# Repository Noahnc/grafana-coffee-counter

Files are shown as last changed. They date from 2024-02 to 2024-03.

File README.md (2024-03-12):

# Grafana Coffee Counter

This project contains all resources to build a Grafana Cloud Coffee Counter.
The coffee counter consists of a custom PCB with an ESP32 and an DFRobot Vibration Sensor.

## How it works

The vibration sensor attached to the coffee machine is connected to the ESP32 and reads the vibration state. If vibration is detected, the ESP32 will count the amount of time the vibration sensor is continuously active. If the vibration sensor is active for more than 8 seconds, the vibration is consideres as a coffee and counters of a Prometheus histogram are increased. Every 60s, a new Time Series is created for the coffee histogram and some other system metrics. The data is then sent to Grafana Cloud Mimir using Prometheus Remote Write. Since the library used for the Prometheus Remote Write is fully Prometheus compatible, the data can technically also be sent to any other Prometheus compatible system. Just make sure to change the URL and the root certificate accordingly.

## Hardware

The following hardware is used for this project:

- https://wiki.dfrobot.com/Vibration_Sensor_SKU_SEN0433
- ESP32 WROVER-E
- Custom PCB (see `./easy_eda`)

## Build Flags

To build this project, you have to create a file called `user_config.ini` in the Project root directory. This file contains the following build flags:

```INI
[user_config]
build_flags =
	-D ENV_GRAFANA_USER=\"<Grafana user>\"
	-D ENV_GRAFANA_PASSWORD=\"<Grafana password>=\"
	-D ENV_WIFI_SSID=\"<Wifi SSID>\"
	-D ENV_WIFI_PASSWORD=\"<Wifi password>!\"
	-D ENV_LABEL_SITE=\"<label value for label SITE>\"
	-D ENV_LABEL_FLOOR=\"<labe value for label FLOOR>\"
	-D ENV_ENABLE_REV2_SENSORS=\"<set true if rev2 board>\"
```

### Hardware & Schema

The design of the custom PCB can be found in the folder `./easy_eda`. The design was created with [EasyEDA](https://easyeda.com/).
In addition to the custom PCB, there are STL files for a 3D-printed case in the folder `./3d_print`.

## CP2102N: USB to UART

The USB-to-UART chip `CP2102N` used in the schema under `./easy_eda` is configured using the [Simplicity Studio Software](https://www.silabs.com/developers/simplicity-studio) from Silicon Labs.

In `./cp2102n_configuration` there is a configuration file that can be played onto the chip with Simplicity Studio Software to set the GPIO configuration for the LED `TXT` and `RXT` and to set device information for the USB protocol. See also [Application Note AN721](https://www.silabs.com/documents/public/application-notes/AN721.pdf) for instructions.

Under Linux it may be necessary to set the execute flag manually for some files:

`chmod -x ./offline/ffd/xpress_configurator/cp210x_base/bin/Linux/*`

In addition, it should be checked whether all dependencies are available:

`ldd ./offline/ffd/xpress_configurator/cp210x_base/bin/Linux/cp210xcfg`

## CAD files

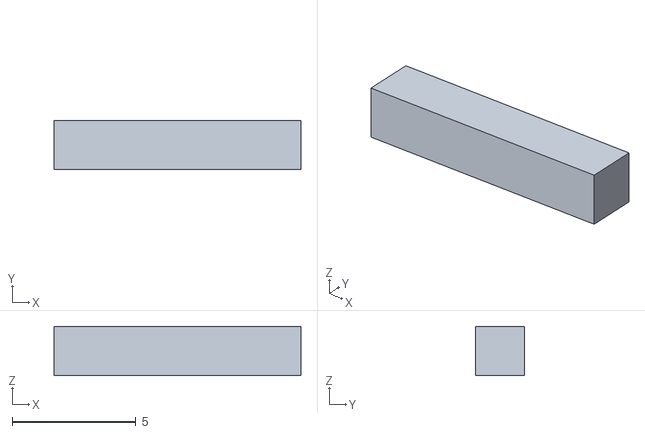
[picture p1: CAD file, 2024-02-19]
3d_print_case/coffee_counter_case_lid.stl
10.0 x 2.00 x 2.00

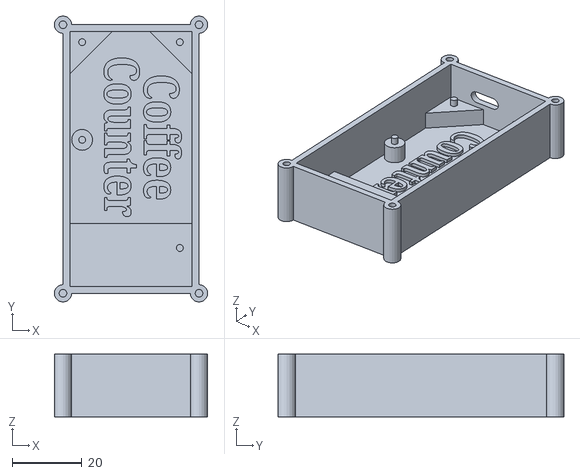
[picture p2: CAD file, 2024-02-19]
3d_print_case/coffee_counter_case.stl
44.0 x 82.0 x 18.0

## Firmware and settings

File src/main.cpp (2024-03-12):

#include <Arduino.h>
#include <PromLokiTransport.h>
#include <PrometheusArduino.h>
#include <config.h>
#include <tuple>
#include <stdio.h>
#include <string>
#include <vector>
#include <sstream>
#include <Wire.h>
#include <arduino-sht.h>
#include <vibration.h>
#include <transport.h>
#include <prometheus_histogram.h>
#include <tuple>
#include "esp32-hal-cpu.h"

// Increase stack size for the main loop since the default 8192 bytes are not enough
SET_LOOP_TASK_STACK_SIZE(32768);

// Function prototypes
#ifdef __cplusplus
  extern "C" {
#endif
  uint8_t temprature_sens_read(); // ES32 provided function to read internal temperature
#ifdef __cplusplus
}
#endif

bool performRemoteWrite();
void handleSampleIngestion();
void handleMetricsSend();
void ingestMetricSample(TimeSeries &ts, int64_t timestamp, double value, String name);
std::vector<std::string> setupLabels();
std::string joinLabels(const std::vector<std::string> &strings);
std::tuple<double, double> getTemperatureAndHumidity();


// I2C Bus & Temp/Humitity sensor
// Do not use bus_num=0 here. Bus 0 seems already to be used by subcomponent of PrometheusArduino or PromLokiTransport.
// Using Bus 1 instead.
TwoWire wire = TwoWire(1);
SHTSensor *sht31 = nullptr;

// Setup time variables
int64_t start_time_unix_ms = 0;
int64_t run_time_ms = 0;
int64_t current_cicle_start_time_unix_ms = 0;
int64_t last_metric_ingestion_unix_ms = 0;
int64_t last_remote_write_unix_ms = 0;

// int to count remote write failures
int remote_write_failures = 0;

// The write request that will be used to send the metrics to Prometheus. For every Histogram you need to add 3 + number of buckets timeseries
WriteRequest req(23, 12288);

// TimeSeries and labels
const char *labels;
Prometheus_Histogram *coffees_consumed = nullptr;
TimeSeries *system_memory_free_bytes = nullptr;
TimeSeries *system_memory_total_bytes = nullptr;
TimeSeries *system_network_wifi_rssi = nullptr;
TimeSeries *system_largest_heap_block_size_bytes = nullptr;
TimeSeries *system_run_time_ms = nullptr;
TimeSeries *system_remote_write_failures_count = nullptr;
TimeSeries *system_cpu_temperature = nullptr;
TimeSeries *system_cpu_clock = nullptr;
TimeSeries *temperature = nullptr;
TimeSeries *humidity = nullptr;

// helper services
hw_timer_t *timer0 = timerBegin(0, 80, true); // timer 0 of esp32 for vibration detection
Vibration *vibration = nullptr;
Transport *transport = nullptr;

void setup()
{
  pinMode(VIBRATION_SENSOR_PIN, INPUT);
  pinMode(VIBRATION_DETECTION_LED_VCC, OUTPUT);
  pinMode(WIFI_STATUS_LED_VCC, OUTPUT);
  pinMode(SYS_STATUS_LED_VCC, OUTPUT);

  // Setup serial
  Serial.begin(SERIAL_BAUD);
  while (!Serial)
    ;

  Serial.println("Starting up coffee counter ...");
  Serial.println("WiFi SSID: " + String(WIFI_SSID));

  std::vector<std::string> labelVector = setupLabels();
  std::string labelString = joinLabels(labelVector);
  labels = labelString.c_str();

  if (DEBUG)
    Serial.println("Labels: " + String(labels));

  // TimeSeries that hold 10 samples. Make sure to set sample_ingestation rate and remote_write_interval accordingly
  coffees_consumed = new Prometheus_Histogram("CMI_coffees_consumed", labels, TIME_SERIES_SAMPLE_COUNT, 12000, 4000, 10);
  system_memory_free_bytes = new TimeSeries(TIME_SERIES_SAMPLE_COUNT, "ESP32_system_memory_free_bytes", labels);
  system_memory_total_bytes = new TimeSeries(TIME_SERIES_SAMPLE_COUNT, "ESP32_system_memory_total_bytes", labels);
  system_network_wifi_rssi = new TimeSeries(TIME_SERIES_SAMPLE_COUNT, "ESP32_system_network_wifi_rssi", labels);
  system_cpu_temperature = new TimeSeries(TIME_SERIES_SAMPLE_COUNT, "ESP32_system_cpu_temperature_celsius", labels);
  system_cpu_clock = new TimeSeries(TIME_SERIES_SAMPLE_COUNT, "ESP32_system_cpu_clock_mhz", labels);
  system_largest_heap_block_size_bytes = new TimeSeries(TIME_SERIES_SAMPLE_COUNT, "ESP32_system_largest_heap_block_size_bytes", labels);
  system_run_time_ms = new TimeSeries(TIME_SERIES_SAMPLE_COUNT, "ESP32_system_run_time_ms", labels);
  system_remote_write_failures_count = new TimeSeries(TIME_SERIES_SAMPLE_COUNT, "ESP32_system_remote_write_failures_count", labels);

  // Add system metrics to the write request
  req.addTimeSeries(*system_memory_free_bytes);
  req.addTimeSeries(*system_memory_total_bytes);
  req.addTimeSeries(*system_network_wifi_rssi);
  req.addTimeSeries(*system_largest_heap_block_size_bytes);
  req.addTimeSeries(*system_run_time_ms);
  req.addTimeSeries(*system_remote_write_failures_count);
  req.addTimeSeries(*system_cpu_temperature);
  req.addTimeSeries(*system_cpu_clock);

  // Setup temperature and humidity sensor with metric if enabled
  if (ENABLE_REV2_SENSORS)
  {
    temperature = new TimeSeries(TIME_SERIES_SAMPLE_COUNT, "coffee_counter_temperature", labels);
    humidity = new TimeSeries(TIME_SERIES_SAMPLE_COUNT, "coffee_counter_humidity", labels);
    req.addTimeSeries(*temperature);
    req.addTimeSeries(*humidity);

    wire.setPins(WIRE_PIN_SDA, WIRE_PIN_SCL);
    wire.begin();
    sht31 = new SHTSensor(SHTSensor::SHT3X);
    sht31->init(wire);
    sht31->setAccuracy(SHTSensor::SHT_ACCURACY_HIGH);
  }

  // setup background task for vibration detection
  vibration = new Vibration(timer0, MOTION_DETECTION_DURATION_THREASHOLD_SECONDS * 1000, coffees_consumed);
  vibration->beginAsync();

  // init coffees_consumed histogram
  coffees_consumed->init(req);

  // setup transportation to Grafana Cloud
  transport = new Transport(WIFI_STATUS_LED_VCC, WIFI_SSID, WIFI_PASSWORD);
  transport->setEndpoint(GC_PORT, GC_URL, (char *)GC_PATH);
  transport->setCredentials(GC_USER, GC_PASS);
  if (DEBUG)
  {
    req.setDebug(Serial);
    transport->setDebug(Serial);
  }
  transport->beginAsync();

  // Set all time variables to the current startup time
  start_time_unix_ms = transport->getTimeMillis();
  last_metric_ingestion_unix_ms = start_time_unix_ms;
  last_remote_write_unix_ms = start_time_unix_ms;

  // set lower CPU lock to reduce power consumtion and heat
  setCpuFrequencyMhz(80);
  Serial.println("Clock speed set to " + String(getCpuFrequencyMhz()) + "Mhz");

  if (DEBUG)
    Serial.println("Startup done");
};

void loop()
{
  if (ENABLE_REV2_SENSORS)
  {
    digitalWrite(SYS_STATUS_LED_VCC, LOW); // low indicates that the main thread is busy, rev2 only
  }

  current_cicle_start_time_unix_ms = transport->getTimeMillis();
  run_time_ms = current_cicle_start_time_unix_ms - start_time_unix_ms;

  handleSampleIngestion();
  handleMetricsSend();

  digitalWrite(SYS_STATUS_LED_VCC, HIGH);
  vTaskDelay(4000 / portTICK_PERIOD_MS);
}

std::vector<std::string> setupLabels()
{
  char instanceLabel[25];
  sprintf(instanceLabel, "instance=\"%012llX\"", ESP.getEfuseMac());

  std::vector<std::string> labels;
  labels.push_back("job=\"cmi_coffee_counter\"");
  labels.push_back(std::string(instanceLabel));
  labels.push_back("site=\"" + std::string(METRICS_LABEL_SITE) + "\"");
  labels.push_back("floor=\"" + std::string(METRICS_LABEL_FLOOR) + "\"");
  return labels;
}

std::string joinLabels(const std::vector<std::string> &strings)
{
  std::ostringstream joined;
  joined << "{";
  for (size_t i = 0; i < strings.size(); ++i)
  {
    joined << strings[i];
    if (i < strings.size() - 1)
    {
      joined << ",";
    }
  }
  joined << "}";
  return joined.str();
}

void handleMetricsSend()
{
  int64_t next_remote_write_ms = last_remote_write_unix_ms + (REMOTE_WRITE_INTERVAL_SECONDS * 1000) - current_cicle_start_time_unix_ms;
  if (next_remote_write_ms > 0)
  {
    if (DEBUG)
      Serial.println("Next remote write in " + String(next_remote_write_ms / 1000) + " seconds");
    return;
  }

  if (DEBUG)
    Serial.println("Performing remote write");

  bool success = performRemoteWrite();
  if (!success)
  {
    remote_write_failures++;
    if (DEBUG)
      Serial.println("Remote Write failed");
    return;
  }
  if (DEBUG)
    Serial.println("Remote Write successful");
  last_remote_write_unix_ms = transport->getTimeMillis();
}

void handleSampleIngestion()
{
  int64_t next_ingestion_ms = last_metric_ingestion_unix_ms + (METRICS_INGESTION_RATE_SECONDS * 1000) - current_cicle_start_time_unix_ms;
  if (next_ingestion_ms > 0)
  {
    if (DEBUG)
      Serial.println("Next metric ingestion in " + String(next_ingestion_ms / 1000) + " seconds");
    return;
  }
  if (DEBUG)
    Serial.println("Ingesting metrics");

  coffees_consumed->Ingest(current_cicle_start_time_unix_ms);
  ingestMetricSample(*system_memory_free_bytes, current_cicle_start_time_unix_ms, ESP.getFreeHeap(), "free_heap_bytes");
  ingestMetricSample(*system_memory_total_bytes, current_cicle_start_time_unix_ms, ESP.getHeapSize(), "total_heap_bytes");
  ingestMetricSample(*system_network_wifi_rssi, current_cicle_start_time_unix_ms, WiFi.RSSI(), "wifi_rssi");
  ingestMetricSample(*system_largest_heap_block_size_bytes, current_cicle_start_time_unix_ms, ESP.getMaxAllocHeap(), "largest_heap_block_bytes");
  ingestMetricSample(*system_run_time_ms, current_cicle_start_time_unix_ms, run_time_ms, "run_time_ms");
  ingestMetricSample(*system_remote_write_failures_count, current_cicle_start_time_unix_ms, remote_write_failures, "remote_write_failures_count");
  ingestMetricSample(*system_cpu_temperature, current_cicle_start_time_unix_ms, (temprature_sens_read()-32)/1.8, "cpu_temperature_celsius");
  ingestMetricSample(*system_cpu_clock, current_cicle_start_time_unix_ms, getCpuFrequencyMhz(), "cpu_clock_mhz");

  if (ENABLE_REV2_SENSORS)
  {
    double temp, hum;
    std::tie(temp, hum) = getTemperatureAndHumidity();
    ingestMetricSample(*temperature, current_cicle_start_time_unix_ms, temp, "temperature");
    ingestMetricSample(*humidity, current_cicle_start_time_unix_ms, hum, "humidity");
  }
  last_metric_ingestion_unix_ms = transport->getTimeMillis();
}

void ingestMetricSample(TimeSeries &ts, int64_t timestamp, double value, String name)
{
  if (ts.addSample(timestamp, value))
  {
    if (DEBUG)
      Serial.println("Ingesting metrics for " + name + ": " + String(value) + " at " + String(timestamp));
  }
  else
  {
    Serial.println("Ingesting metrics: Failed to add sample" + String(ts.errmsg));
  }
}

std::tuple<double, double> getTemperatureAndHumidity()

{
  sht31->readSample();
  double temperature = sht31->getTemperature();
  double humidity = sht31->getHumidity();
  if (DEBUG)
    Serial.println("Temperature: " + String(temperature) + " Humidity: " + String(humidity) + " at " + String(transport->getTimeMillis()) + " ms");
  return std::make_tuple(temperature, humidity);
}

bool performRemoteWrite()
{
  PromClient::SendResult res = transport->send(req);
  if (!res == PromClient::SendResult::SUCCESS)
  {
    return false;
  }
  coffees_consumed->resetSamples();
  system_memory_free_bytes->resetSamples();
  system_memory_total_bytes->resetSamples();
  system_network_wifi_rssi->resetSamples();
  system_largest_heap_block_size_bytes->resetSamples();
  system_run_time_ms->resetSamples();
  system_remote_write_failures_count->resetSamples();
  system_cpu_temperature->resetSamples();
  system_cpu_clock->resetSamples();
  temperature->resetSamples();
  humidity->resetSamples();
  return true;
}

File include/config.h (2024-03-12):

// Wifi config of the esp32
#define WIFI_SSID ENV_WIFI_SSID
#define WIFI_PASSWORD ENV_WIFI_PASSWORD

// For more information on where to get these values see: https://github.com/grafana/diy-iot/blob/main/README.md#sending-metrics
#define GC_URL "prometheus-prod-22-prod-eu-west-3.grafana.net"
#define GC_PATH "/api/prom/push"
#define GC_PORT 443
#define GC_USER ENV_GRAFANA_USER
#define GC_PASS ENV_GRAFANA_PASSWORD

// enable temperature and humidity sensor
#define ENABLE_REV2_SENSORS ENV_ENABLE_REV2_SENSORS

// Enable debug logging to serial
#define DEBUG true
#define SERIAL_BAUD MONITOR_SPEED

// Interval in seconds between sending metrics to Grafana Cloud
#define REMOTE_WRITE_INTERVAL_SECONDS 180

// Metrics Ingestion Rate
#define METRICS_INGESTION_RATE_SECONDS 60

// Metric label value for the site
#define METRICS_LABEL_SITE ENV_LABEL_SITE

// Metric label value for the floor
#define METRICS_LABEL_FLOOR ENV_LABEL_FLOOR

// Amount of time in seconds vibration must be detected to be considered as vibration event
#define MOTION_DETECTION_DURATION_THREASHOLD_SECONDS 8

// Pin to which the vibration sensor is connected
#define VIBRATION_SENSOR_PIN 36
// Pin connected to a LED to indicated that vibration is detected
#define VIBRATION_DETECTION_LED_VCC 25

// Pin to indicate WIFI status
#define WIFI_STATUS_LED_VCC 26

// Pins to indicate the system is booted (REV 2 only)
#define SYS_STATUS_LED_VCC 27

// The number samples all time series can hold
#define TIME_SERIES_SAMPLE_COUNT 10

// Pins used for the I2C bus
#define WIRE_PIN_SDA 32
#define WIRE_PIN_SCL 33

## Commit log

2023-12-26 Add std. esp32 dev kit environment
2023-12-26 sensor reading moved to task
2024-01-06 Update BOM and PCB
2024-01-13 fix(headers): Add header for new method.
    [main.cpp]
2024-01-13 fix(system_metrics): switch from mb to bytes.
    [main.cpp]
2024-01-13 fix(system_metrics): Add metrics to request and reset series after send.
    [main.cpp]
2024-01-14 feat(main): Update main * Remove heltec board. * Add additional counters. * Refactor metric ingestion.
2024-01-15 feat(coffee_metrics): Switch from individual metrics to an additional label for the coffee size.
2024-01-15 fix(series): Fix string concat.
    [main.cpp]
2024-01-15 fix(labels): Hardcode labels instead of concat them because of problem with strcat and strcpy.
    [main.cpp]
2024-01-18 Wifi Led: indicate bad wifi connection
2024-01-20 feat(main): replace individual coffee counters with histogramm
    [main.cpp]
2024-01-20 feat(main): Remove no longer needed counters for coffee sizes
    [main.cpp]
2024-01-20 fix(histogramm): Set bucket counters to 0 on init.
2024-01-20 feat(main): * Add comments. * Set all time variables to startup time in setup. * Switch Histogramm input form seconds to ms.
2024-01-20 feat(vibration_detection): Add unit to print msg.
2024-01-20 enable esp32 crash decoder
2024-01-20 feat(histogramm): Switch count and sum series to pointer, since this seems to resolve the random memory error during sample ingestion.
2024-01-21 fix(stack_size): Increase stack size of the main loop since 8192 bytes was not enaugh to remote write all series.
    [main.cpp]
2024-01-21 fix vibration detect not yielding
    [main.cpp]
2024-01-21 feat(system_metrics): Add additional system metrics for uptime and remote write failures.
    [main.cpp]
2024-01-21 fix(metric_ingestion): Cancle sample ingestion if semaphore could not be taken. This ensures that the last_metric_ingestion_unix_ms is not updated and the sample ingestion retried in the next cycle.
    [main.cpp]
2024-01-21 fix(remote_write): Return function if remote write failed.
    [main.cpp]
2024-01-21 fix(Gramar): Rename Histogramm to Histogram
    [main.cpp, prometheus_histogram.cpp]
2024-01-21 refactor to "vibration" class
    [main.cpp, vibration.cpp]
2024-01-21 Fixing reference to null pointer
    [main.cpp, prometheus_histogram.cpp, vibration.cpp]
2024-01-21 Fix build warning const char* to char*
    [prometheus_histogram.cpp]
2024-01-23 feat(time_series_sample_size): Move sample size for series into variable and increase count to 10.
2024-01-23 feat(coffees_consumed_histogram): Increase bucket start to 14000 and increase increment to 5000
2024-01-23 feat(labels): Print label string on startup.
2024-01-23 fix(histogram): Append _bucket to bucket metric name.
    [prometheus_histogram.cpp]
2024-01-25 Fix null pointer exeception on release build
    [transport.cpp]
2024-01-25 fix(Histogram): Increase value to 64bit int
    [prometheus_histogram.cpp]
2024-01-31 fix(WriteRequest): Increase write request by one since we have 19 series, not 18
    [main.cpp]
2024-01-31 feat(case): Add stl files and doc for 3d printed case.
    [coffee_counter_case.stl, coffee_counter_case_lid.stl]
2024-01-31 doc(README): clarify that the sensor is attached to the coffee machine.
2024-02-28 Use sys led in main loop
2024-02-28 Setup wire and sht31 sensor
2024-03-02 feat(build_flag): Add new build flag to enable rev2 sensors
2024-03-02 feat(temp_sensor): Add metric for temp and humidity sensor
2024-03-04 Add missing read command from sht31
    [main.cpp]
2024-03-06 feat(temperature_metric): Add coffee_counter prefix
2024-03-07 Fix datatype, addSample takes double
    [main.cpp]
2024-03-11 Add system temperature to metrics
2024-03-12 pcb, remove copper area around sht31
